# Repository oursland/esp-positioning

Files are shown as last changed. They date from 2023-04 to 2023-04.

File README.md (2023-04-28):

# Positioning via IMU-aided WiFi FTM and UWB on an ESP32-S3

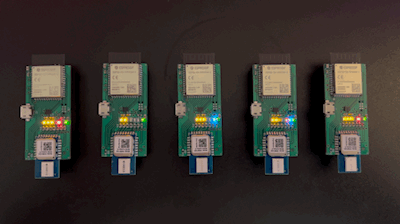
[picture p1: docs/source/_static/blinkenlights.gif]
blinkenlights


## Overview

There is ample research into the accuracy of Ulra Wideband (UWB)-based ranging and positioning, WiFi Fine Timing Measurements (WiFi FTM)-based ranging and positioning, and an Inertial Measurement Unit (IMU) augmentation of such systems.  Most of the work was performed with purpose-designed systems or smartphones, but very little was performed using Espressif SoCs including the ESP32-S3.

Based on the findings of previous works, it's expected that WiFi FTM may be only valuable for positioning information to about 1 meter accuracy while UWB sensors can provide measurements accurate down to around 10 centimeters.  UWB has limited range, particularly in indoor and cluttered environments where the signals fail to penetrate through walls or other obstacles.  This suggests that if accuracy is a requirement, it may be required to install a UWB transciever but also utilize WiFi FTM to provide rough positioning should the UWB signal be lost.

Sensor fusion and state estimation through Kalman filtering can provide better positioning estimates over naive approaches using WiFi FTM, UWB, or IMU measurements alone.  Previous research have been performed using Extended Kalman Filtering (EKF) and Unscented Kalman Filter (UKF) approaches, but publications for Invariant Extended Kalman Filter (InEKF) have not been identified.

### Questions

1. Given the utility for low-cost, low-power, and reduced bill-of-materials positioning for small, low-cost robots, can we use the ESP32-S3's WiFi Fine Timing Measurements (WiFi FTM) in 802.11mc standard and an IMU for positioning without additional sensors?

2. Will the inclusion of a UWB sensor bring sufficient value to offset their additional cost, complexity, and power consumption?

3. Can the redundancy in Time Difference of Arrival (TDOA) measurements from WiFi FTM and UWB be used to improve accuracy beyond either WiFi FTM or UWB alone?

## Objective

This experiment is to compare and contrast position estimation of systems:

    1. IMU and WiFi FTM
    2. IMU and UWB
    3. IMU with WiFi FTM and UWB

## Experiment Design

To perform this experiment, a custom design was created using:

* Espressif ESP32-S3-WROOM-2 module
* STMicroelectronics ISM330DHCX IMU
* Qorvo DWM1000 UWB module
* 2 AAA battery holder

Circuit Diagram and PCB Layout can be found in the [`kicad/`](kicad/) directory.

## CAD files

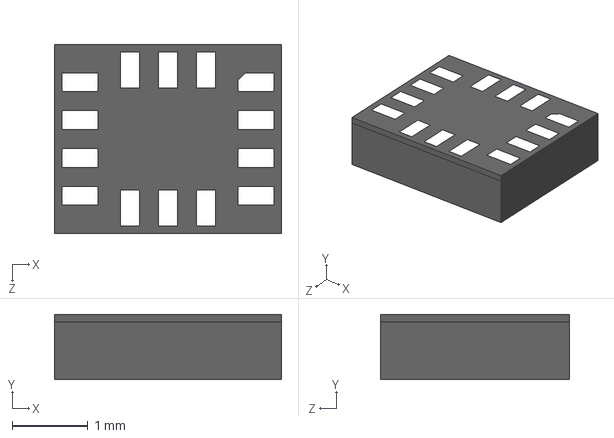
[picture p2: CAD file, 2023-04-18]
kicad/3D/ISM330DHCXTR.stp
3.00 x 0.86 x 2.50 mm

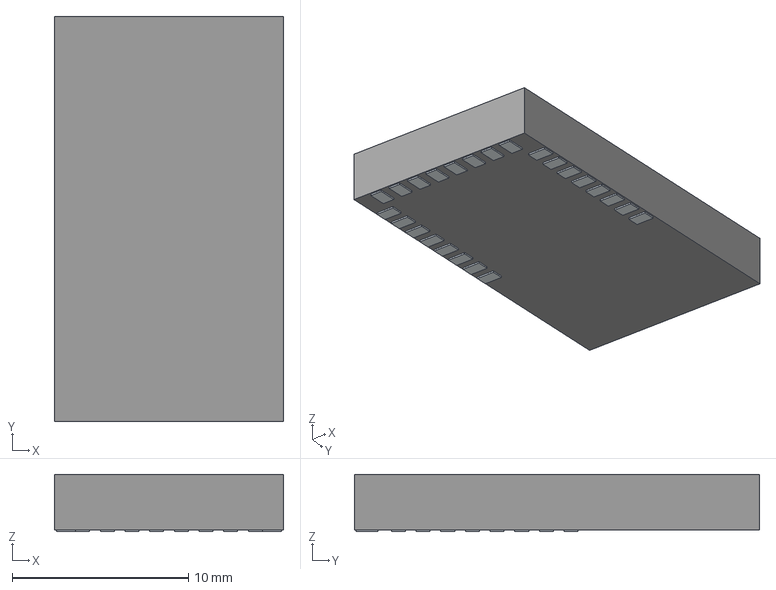
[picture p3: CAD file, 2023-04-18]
kicad/3D/DWM1000.stp
13.0 x 23.0 x 3.25 mm
Pins

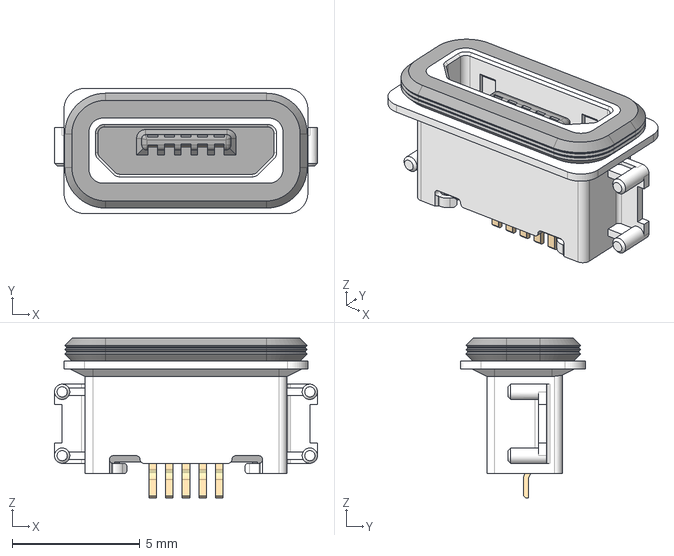
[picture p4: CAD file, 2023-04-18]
kicad/3D/USB3500-30-A.stp
10.3 x 4.90 x 6.25 mm
ÇÐ³ý-ÀÉì3
µ¹½Ç2

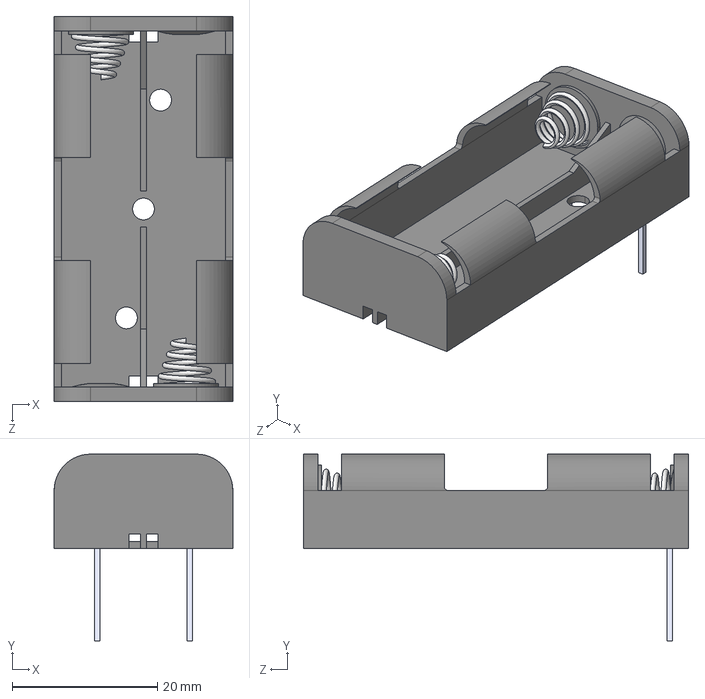
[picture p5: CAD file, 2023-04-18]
kicad/3D/2468.stp
24.6 x 25.7 x 53.0 mm

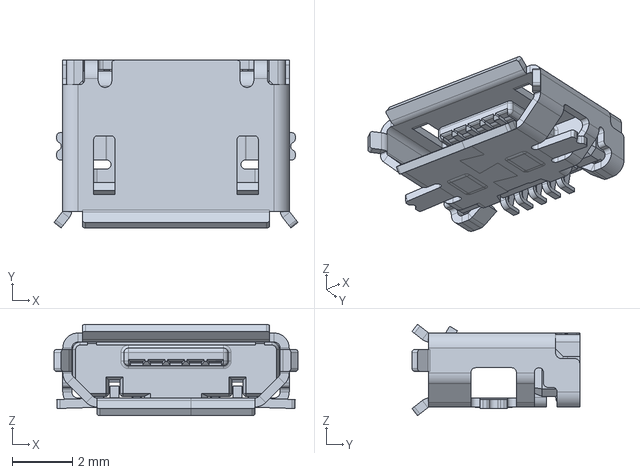
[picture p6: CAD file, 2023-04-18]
kicad/3D/10104110-0001LF.stp
8.08 x 5.56 x 3.03 mm

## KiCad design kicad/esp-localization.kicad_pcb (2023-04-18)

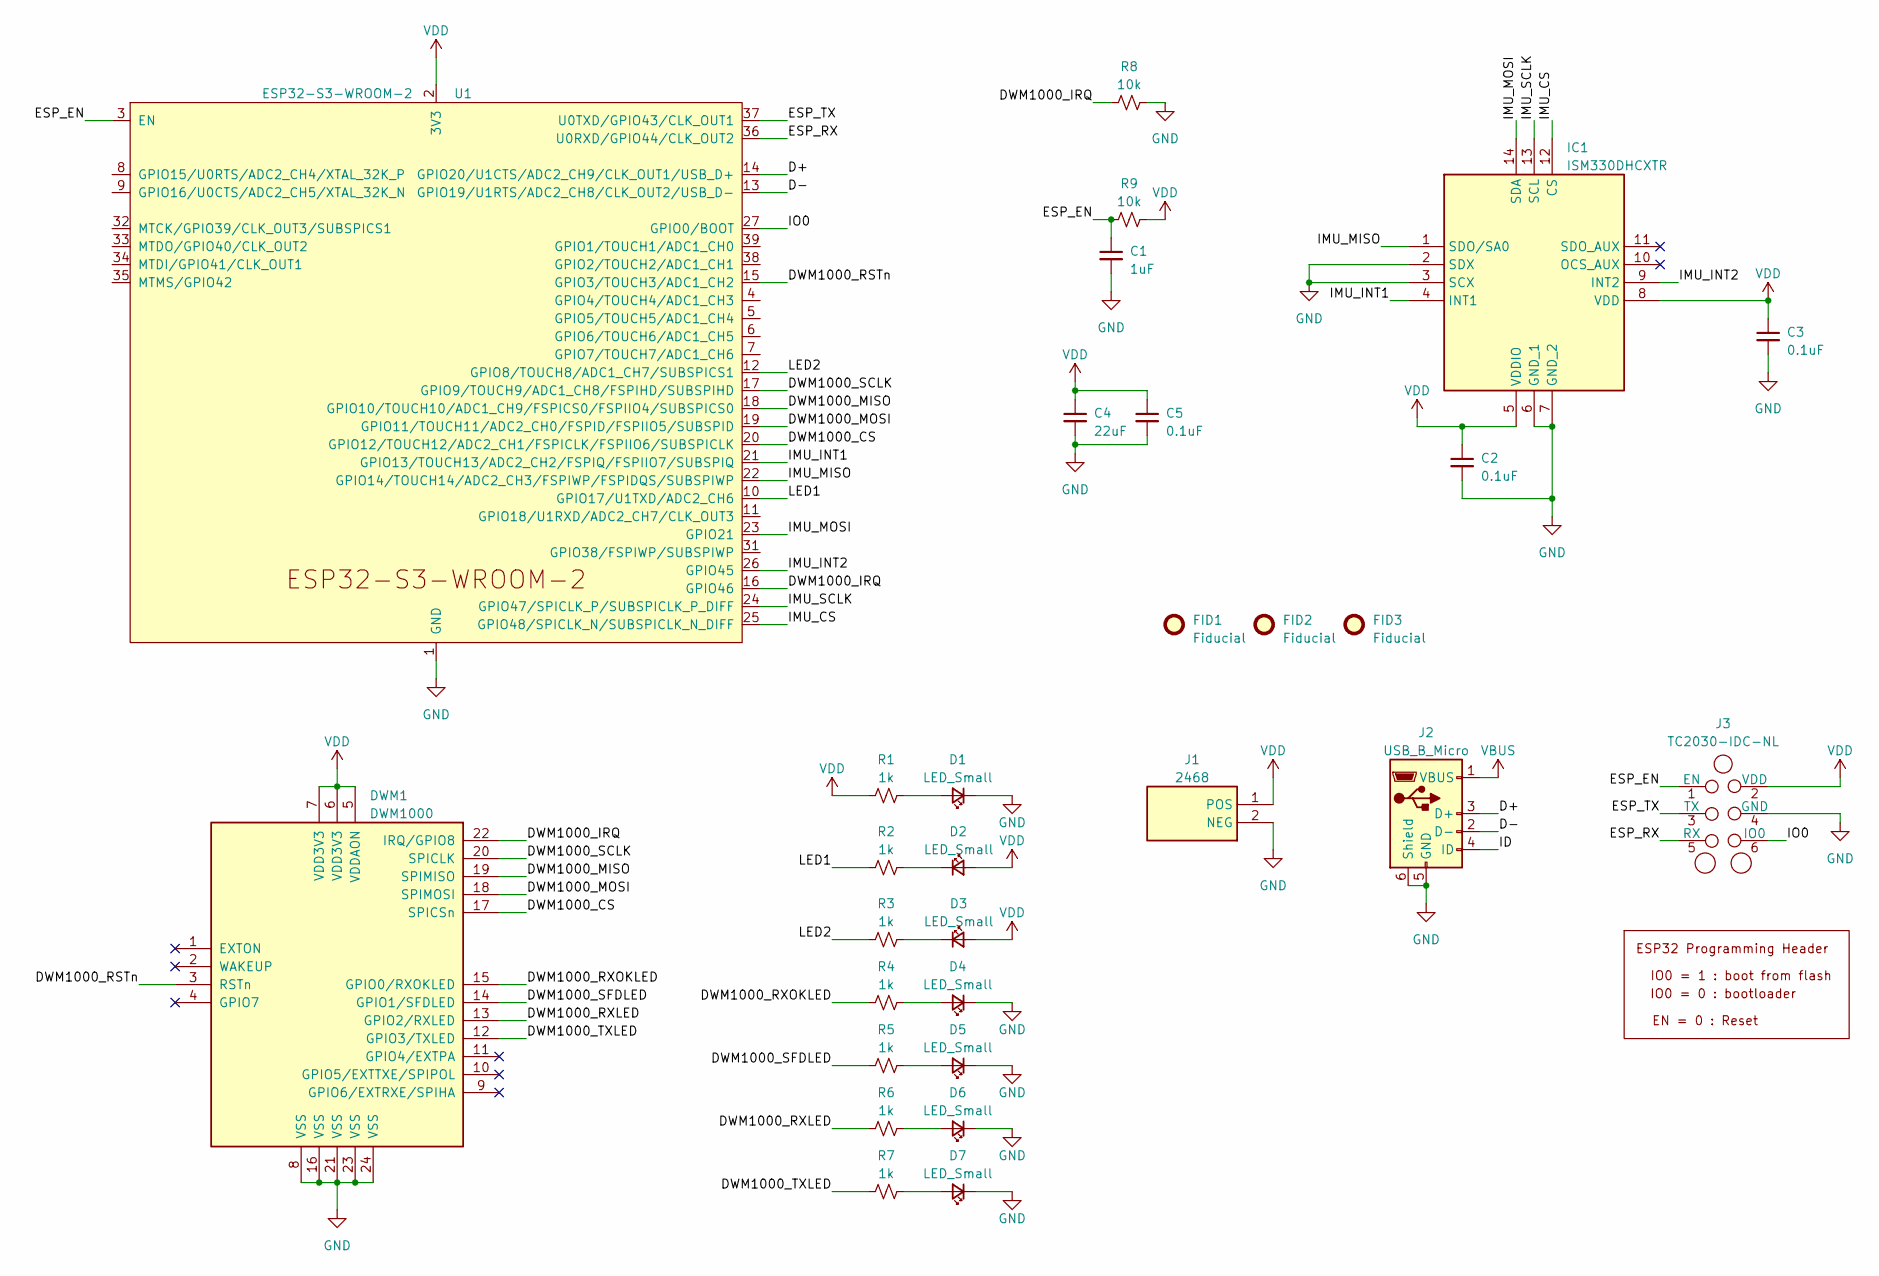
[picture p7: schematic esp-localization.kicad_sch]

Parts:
C1: 1uF; C_0805_2012Metric
C2, C3, C5: 0.1uF; C_0603_1608Metric
C4: 22uF; C_0805_2012Metric
D1, D2, D3, D4, D5, D6, D7: LED_Small; LED_0603_1608Metric
DWM1: DWM1000
FID1, FID2, FID3: Fiducial; Fiducial_0.5mm_Mask1mm
IC1: ISM330DHCXTR; LGA-14_2.5X3X0.86_; Mouser Part Number 511-ISM330DHCXTR
J1: 2468; Mouser Part Number 534-2468
J2: USB_B_Micro; USB_Micro-B_Amphenol_10104110_Horizontal
J3: TC2030-IDC-NL_ESP; Tag-Connect_TC2030-IDC-NL_2x03_P1.27mm_Vertical
R1, R2, R3, R4, R5, R6, R7: 1k; R_0603_1608Metric
R8, R9: 10k; R_0603_1608Metric
U1: ESP32-S3-WROOM-2

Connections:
/D+: J2.3 (D+), U1.14 (GPIO20/U1CTS/ADC2_CH9/CLK_OUT1/USB_D+)
/D-: J2.2 (D-), U1.13 (GPIO19/U1RTS/ADC2_CH8/CLK_OUT2/USB_D-)
/DWM1000_CS: DWM1.17 (SPICSn), U1.20 (GPIO12/TOUCH12/ADC2_CH1/FSPICLK/FSPIIO6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)
/DWM1000_IRQ: DWM1.22 (IRQ/GPIO8), R8.1, U1.16 (GPIO46)
/DWM1000_MISO: DWM1.19 (SPIMISO), U1.18 (GPIO10/TOUCH10/ADC1_CH9/FSPICS0/FSPIIO4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)
/DWM1000_MOSI: DWM1.18 (SPIMOSI), U1.19 (GPIO11/TOUCH11/ADC2_CH0/FSPID/FSPIIO5/S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)
/DWM1000_RSTn: DWM1.3 (RSTn), U1.15 (GPIO3/TOUCH3/ADC1_CH2)
/DWM1000_RXLED: DWM1.13 (GPIO2/RXLED), R6.1
/DWM1000_RXOKLED: DWM1.15 (GPIO0/RXOKLED), R4.1
/DWM1000_SCLK: DWM1.20 (SPICLK), U1.17 (GPIO9/TOUCH9/ADC1_CH8/FSPIHD/SUBSPIHD)
/DWM1000_SFDLED: DWM1.14 (GPIO1/SFDLED), R5.1
/DWM1000_TXLED: DWM1.12 (GPIO3/TXLED), R7.1
/ESP_EN: C1.1, J3.1 (EN), R9.1, U1.3 (EN)
/ESP_RX: J3.5 (RX), U1.36 (U0RXD/GPIO44/CLK_OUT2)
/ESP_TX: J3.3 (TX), U1.37 (U0TXD/GPIO43/CLK_OUT1)
/ID: J2.4 (ID)
/IMU_CS: IC1.12 (CS), U1.25 (GPIO48/SPICLK_N/SUBSPICLK_N_DIFF)
/IMU_INT1: IC1.4 (INT1), U1.21 (GPIO13/TOUCH13/ADC2_CH2/FSPIQ/FSPIIO7/S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)
/IMU_INT2: IC1.9 (INT2), U1.26 (GPIO45)
/IMU_MISO: IC1.1 (SDO/SA0), U1.22 (GPIO14/TOUCH14/ADC2_CH3/FSPIWP/FSPIDQS/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)
/IMU_MOSI: IC1.14 (SDA), U1.23 (GPIO21)
/IMU_SCLK: IC1.13 (SCL), U1.24 (GPIO47/SPICLK_P/SUBSPICLK_P_DIFF)
/IO0: J3.6 (IO0), U1.27 (GPIO0/BOOT)
/LED1: R2.1, U1.10 (GPIO17/U1TXD/ADC2_CH6)
/LED2: R3.1, U1.12 (GPIO8/TOUCH8/ADC1_CH7/SUBSPICS1)
GND: C1.2, C2.2, C3.2, C4.2, C5.2, D1.1 (K), D4.1 (K), D5.1 (K), D6.1 (K), D7.1 (K), DWM1.8 (VSS), DWM1.16 (VSS), DWM1.21 (VSS), DWM1.23 (VSS), DWM1.24 (VSS), IC1.2 (SDX), IC1.3 (SCX), IC1.6 (GND_1), IC1.7 (GND_2), J1.2 (NEG), J2.5 (GND), J2.6 (Shield), J3.4 (GND), R8.2, U1.1 (GND), U1.40 (GND), U1.41 (GND)
unnamed: D1.2 (A), R1.2
unnamed: D2.1 (K), R2.2
unnamed: D3.1 (K), R3.2
unnamed: D4.2 (A), R4.2
unnamed: D5.2 (A), R5.2
unnamed: D6.2 (A), R6.2
unnamed: D7.2 (A), R7.2
VBUS: J2.1 (VBUS)
VDD: C2.1, C3.1, C4.1, C5.1, D2.2 (A), D3.2 (A), DWM1.5 (VDDAON), DWM1.6 (VDD3V3), DWM1.7 (VDD3V3), IC1.5 (VDDIO), IC1.8 (VDD), J1.1 (POS), J3.2 (VDD), R1.1, R9.2, U1.2 (3V3)

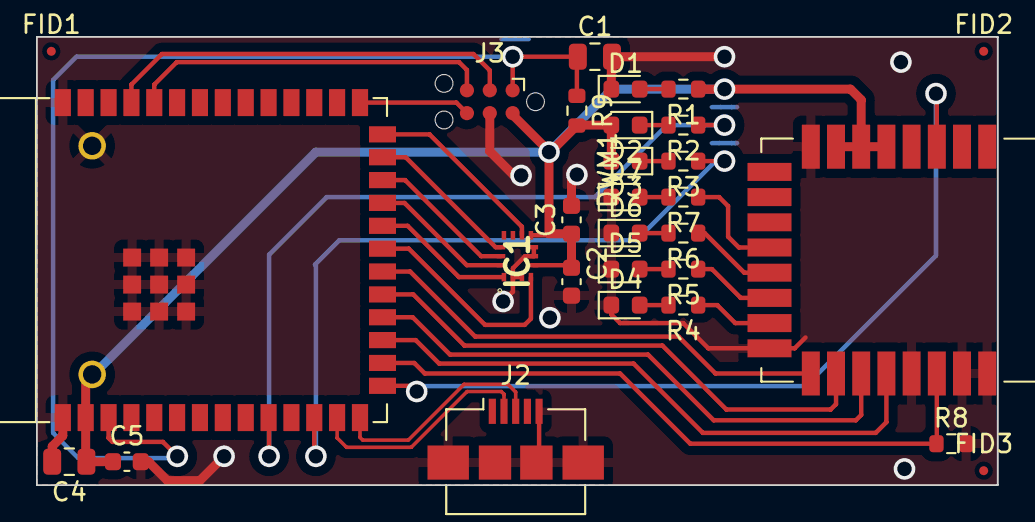
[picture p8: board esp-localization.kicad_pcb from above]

Board: 2 copper layers, 53.4 x 24.9 mm, 30 parts (1 on the bottom side), 33 nets.

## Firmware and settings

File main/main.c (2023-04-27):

#include <stdio.h>
#include <stdlib.h>
#include <string.h>
#include <inttypes.h>

#include "sdkconfig.h"

#include "freertos/FreeRTOS.h"
#include "freertos/queue.h"
#include "freertos/task.h"

#include "esp_chip_info.h"
#include "esp_flash.h"
#include "esp_log.h"
#include "esp_mac.h"
#include "esp_timer.h"
#include "nvs_flash.h"

#include "driver/gpio.h"

#include "common.h"
#include "dw1000-task.h"
#include "ftm-task.h"
#include "ism330dhcx-task.h"

#define TAG         "app_main"

// LEDs are active low
#define LED1        GPIO_NUM_17
#define LED2        GPIO_NUM_8

void app_main()
{
    /* Print chip information */
    esp_chip_info_t chip_info;
    uint32_t flash_size;
    esp_chip_info(&chip_info);
    ESP_LOGI(TAG, "This is %s chip with %d CPU core(s), WiFi%s%s%s, ",
        CONFIG_IDF_TARGET,
        chip_info.cores,
        (chip_info.features & CHIP_FEATURE_BT) ? "/BT" : "",
        (chip_info.features & CHIP_FEATURE_BLE) ? "/BLE" : "",
        (chip_info.features & CHIP_FEATURE_IEEE802154) ? ", 802.15.4 (Zigbee/Thread)" : "");

    unsigned major_rev = chip_info.revision / 100;
    unsigned minor_rev = chip_info.revision % 100;
    ESP_LOGI(TAG, "silicon revision v%d.%d, ", major_rev, minor_rev);
    if(esp_flash_get_size(NULL, &flash_size) != ESP_OK) {
        printf("Get flash size failed");
        return;
    }

    ESP_LOGI(TAG, "%" PRIu32 "MB %s flash", flash_size / (uint32_t)(1024 * 1024),
        (chip_info.features & CHIP_FEATURE_EMB_FLASH) ? "embedded" : "external");

    ESP_LOGI(TAG, "Minimum free heap size: %" PRIu32 " bytes", esp_get_minimum_free_heap_size());

    uint8_t mac[6];
    ESP_ERROR_CHECK(esp_read_mac(mac, ESP_MAC_BASE));
    ESP_LOGI(TAG, "MAC address: [%02X:%02X:%02X:%02X:%02X:%02X]", mac[0], mac[1], mac[2], mac[3], mac[4], mac[5]);

    esp_err_t ret = nvs_flash_init();
    if(ret == ESP_ERR_NVS_NO_FREE_PAGES || ret == ESP_ERR_NVS_NEW_VERSION_FOUND) {
        ESP_ERROR_CHECK(nvs_flash_erase());
        ret = nvs_flash_init();
    }
    ESP_ERROR_CHECK(ret);

    // LEDS
    bool led1 = 0;
    bool led2 = 0;

    gpio_set_direction(LED1, GPIO_MODE_OUTPUT);
    gpio_set_level(LED1, led1);

    gpio_set_direction(LED2, GPIO_MODE_OUTPUT);
    gpio_set_level(LED2, led2);

    task_t ism330dhcx_task;
    task_t ftm_task;
    task_t dw1000_task;

    QueueHandle_t main_queue = xQueueCreate(10, sizeof(event_type_t));

    ism330dhcx_task.task_queue = xQueueCreate(10, sizeof(event_type_t));
    ism330dhcx_task.main_queue = main_queue;
    ism330dhcx_task.task_handle = xTaskCreate(ism330dhcx_task_func, "ism330dhcx_task", 4096, &ism330dhcx_task, 1, NULL);

    ftm_task.task_queue = xQueueCreate(10, sizeof(event_type_t));
    ftm_task.main_queue = main_queue;
    ftm_task.task_handle = xTaskCreate(ftm_task_func, "ftm_task", 4096, &ftm_task, 1, NULL);

    dw1000_task.task_queue = xQueueCreate(10, sizeof(event_type_t));
    dw1000_task.main_queue = main_queue;
    dw1000_task.task_handle = xTaskCreate(dw1000_task_func, "dw1000_task", 4096, &dw1000_task, 1, NULL);

    for(;;) {
        led1 = !led1;
        gpio_set_level(LED1, led1);

        vTaskDelay(pdMS_TO_TICKS(100));
    }
}

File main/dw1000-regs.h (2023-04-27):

#pragma once

/*
 * Driver for decaWave DW1000 802.15.4 UWB radio chip.
 *
 * Copyright (c) 2016 Bitcraze AB
 * Converted to C from  the Decawave DW1000 library for arduino.
 * which is Copyright (c) 2015 by Thomas Trojer <thomas@trojer.net>
 *
 * Licensed under the Apache License, Version 2.0 (the "License");
 * you may not use this file except in compliance with the License.
 * You may obtain a copy of the License at
 *
 *     http://www.apache.org/licenses/LICENSE-2.0
 *
 * Unless required by applicable law or agreed to in writing, software
 * distributed under the License is distributed on an "AS IS" BASIS,
 * WITHOUT WARRANTIES OR CONDITIONS OF ANY KIND, either express or implied.
 * See the License for the specific language governing permissions and
 * limitations under the License.
 */

// Time resolution in micro-seconds of time based registers/values.
// Each bit in a timestamp counts for a period of approx. 15.65ps
#define TIME_RES 0.000015650040064103
#define TIME_RES_INV 63897.6

// Speed of radio waves [m/s] * timestamp resolution [~15.65ps] of DW1000
#define DISTANCE_OF_RADIO 0.0046917639786159f
#define DISTANCE_OF_RADIO_INV 213.139451293f

// time stamp byte length
#define LEN_STAMP 5

// enum to determine RX or TX mode of device
#define IDLE_MODE 0x00
#define RX_MODE 0x01
#define TX_MODE 0x02

// used for SPI ready w/o actual writes
#define JUNK 0x00

// no sub-address for register write
#define NO_SUB 0x00

// device id register
#define DEV_ID 0x00
#define LEN_DEV_ID 4

// extended unique identifier register
#define EUI 0x01
#define LEN_EUI 8

// PAN identifier, short address register
#define PANADR 0x03
#define LEN_PANADR 4

// device configuration register
#define SYS_CFG 0x04
#define LEN_SYS_CFG 4
#define FFEN_BIT 0
#define FFBC_BIT 1
#define FFAB_BIT 2
#define FFAD_BIT 3
#define FFAA_BIT 4
#define FFAM_BIT 5
#define FFAR_BIT 6
#define SPI_EDGE_BIT 10
#define DIS_DRXB_BIT 12
#define DIS_STXP_BIT 18
#define HIRQ_POL_BIT 9
#define RXAUTR_BIT 29
#define PHR_MODE_SUB 16
#define LEN_PHR_MODE_SUB 2
#define RXM110K_BIT 22
#define RXWTOE_BIT 28

// device control register
#define SYS_CTRL 0x0D
#define LEN_SYS_CTRL 4
#define SFCST_BIT 0
#define TXSTRT_BIT 1
#define TXDLYS_BIT 2
#define TRXOFF_BIT 6
#define WAIT4RESP_BIT 7
#define RXENAB_BIT 8
#define RXDLYS_BIT 9

// system event status register
#define SYS_STATUS 0x0F
#define LEN_SYS_STATUS 5
#define CPLOCK_BIT 1
#define AAT_BIT 3
#define TXFRB_BIT 4
#define TXPRS_BIT 5
#define TXPHS_BIT 6
#define TXFRS_BIT 7
#define RXPRD_BIT 8
#define MRXSFDD_BIT 9
#define LDEDONE_BIT 10
#define MRXPHD_BIT 11
#define RXPHE_BIT 12
#define RXDFR_BIT 13
#define RXFCG_BIT 14
#define RXFCE_BIT 15
#define RXRFSL_BIT 16
#define RXRFTO_BIT 17
#define LDEERR_BIT 18
// Bit 19 is reserved
#define RXOVRR_BIT 20
#define RXPTO_BIT 21
#define RFPLL_LL_BIT 24
#define CLKPLL_LL_BIT 25
#define RXSFDTO_BIT 26
#define AFFREJ_BIT 29

// Helper masks. See: See: https://github.com/Decawave/dwm1001-examples/blob/master/deca_driver/deca_regs.h
// All RX errors mask
#define SYS_STATUS_ALL_RX_ERR (1 << RXPHE_BIT | 1 << RXFCE_BIT | 1 << RXRFSL_BIT | 1 << RXSFDTO_BIT | 1 << AFFREJ_BIT | 1 << LDEERR_BIT)
// User defined RX timeouts (frame wait timeout and preamble detect timeout) mask
#define SYS_STATUS_ALL_RX_TO (1 << RXRFTO_BIT | 1 << RXPTO_BIT)
// All RX events after a correct packet reception mask
#define SYS_STATUS_ALL_RX_GOOD (1 << RXDFR_BIT | 1 << RXFCG_BIT | 1 << RXPRD_BIT | 1 << MRXSFDD_BIT | 1 << MRXPHD_BIT | 1 << LDEDONE_BIT)
// All TX events mask
#define SYS_STATUS_ALL_TX (1 << AAT_BIT | 1 << TXFRB_BIT | 1 << TXPRS_BIT | 1 << TXPHS_BIT | 1 << TXFRS_BIT)

// GPIO control register
#define GPIO_CTRL 0x26
#define GPIO_MODE_SUB 0x00
#define LEN_GPIO_MODE 4
#define GPIO_DIR_SUB 0x08
#define LEN_GPIO_DIR 4


// system event mask register
// NOTE: uses the bit definitions of SYS_STATUS (below 32)
#define SYS_MASK 0x0E
#define LEN_SYS_MASK 4

// system time counter
#define SYS_TIME 0x06
#define LEN_SYS_TIME LEN_STAMP

// RX timestamp register
#define RX_TIME 0x15
#define LEN_RX_TIME 14
#define RX_STAMP_SUB 0x00
#define FP_AMPL1_SUB 0x07
#define LEN_RX_STAMP LEN_STAMP
#define LEN_FP_AMPL1 2

// RX frame quality
#define RX_FQUAL 0x12
#define LEN_RX_FQUAL 8
#define STD_NOISE_SUB 0x00
#define FP_AMPL2_SUB 0x02
#define FP_AMPL3_SUB 0x04
#define CIR_PWR_SUB 0x06
#define LEN_STD_NOISE 2
#define LEN_FP_AMPL2 2
#define LEN_FP_AMPL3 2
#define LEN_CIR_PWR 2

// TX timestamp register
#define TX_TIME 0x17
#define LEN_TX_TIME 10
#define TX_STAMP_SUB 0
#define LEN_TX_STAMP LEN_STAMP

// timing register (for delayed RX/TX)
#define DX_TIME 0x0A
#define LEN_DX_TIME LEN_STAMP

// transmit data buffer
#define TX_BUFFER 0x09
#define LEN_TX_BUFFER 1024
#define LEN_UWB_FRAMES 127
#define LEN_EXT_UWB_FRAMES 1023

// Receive frame ait timeout period
#define RX_FWTO 0x0C

// RX frame info
#define RX_FINFO 0x10
#define LEN_RX_FINFO 4

// receive data buffer
#define RX_BUFFER 0x11
#define LEN_RX_BUFFER 1024

// transmit control
#define TX_FCTRL 0x08
#define LEN_TX_FCTRL 5

// channel control
#define CHAN_CTRL 0x1F
#define LEN_CHAN_CTRL 4
#define DWSFD_BIT 17
#define TNSSFD_BIT 20
#define RNSSFD_BIT 21

// user-defined SFD
#define USR_SFD 0x21
#define LEN_USR_SFD 41
#define SFD_LENGTH_SUB 0x00
#define LEN_SFD_LENGTH 1

// OTP control (for LDE micro code loading only)
#define OTP_IF 0x2D
#define OTP_ADDR_SUB 0x04
#define OTP_CTRL_SUB 0x06
#define OTP_RDAT_SUB 0x0A
#define LEN_OTP_ADDR 2
#define LEN_OTP_CTRL 2
#define LEN_OTP_RDAT 4

// AGC_TUNE1/2 (for re-tuning only)
#define AGC_TUNE 0x23
#define AGC_TUNE1_SUB 0x04
#define AGC_TUNE2_SUB 0x0C
#define AGC_TUNE3_SUB 0x12
#define LEN_AGC_TUNE1 2
#define LEN_AGC_TUNE2 4
#define LEN_AGC_TUNE3 2

// DRX_TUNE2 (for re-tuning only)
#define DRX_TUNE 0x27
#define DRX_TUNE0b_SUB 0x02
#define DRX_TUNE1a_SUB 0x04
#define DRX_TUNE1b_SUB 0x06
#define DRX_TUNE2_SUB 0x08
#define DRX_TUNE4H_SUB 0x26
#define LEN_DRX_TUNE0b 2
#define LEN_DRX_TUNE1a 2
#define LEN_DRX_TUNE1b 2
#define LEN_DRX_TUNE2 4
#define LEN_DRX_TUNE4H 2

// LDE_CFG1 (for re-tuning only)
#define LDE_IF 0x2E
#define LDE_CFG1_SUB 0x0806
#define LDE_RXANTD_SUB 0x1804
#define LDE_CFG2_SUB 0x1806
#define LDE_REPC_SUB 0x2804
#define LEN_LDE_CFG1 1
#define LEN_LDE_CFG2 2
#define LEN_LDE_REPC 2
#define LEN_LDE_RXANTD 2

// TX_POWER (for re-tuning only)
#define TX_POWER 0x1E
#define LEN_TX_POWER 4

// RF_CONF (for re-tuning only)
#define RF_CONF 0x28
#define RF_RXCTRLH_SUB 0x0B
#define RF_TXCTRL_SUB 0x0C
#define LEN_RF_RXCTRLH 1
#define LEN_RF_TXCTRL 4

// TX_CAL (for re-tuning only)
#define TX_CAL 0x2A
#define TC_PGDELAY_SUB 0x0B
#define LEN_TC_PGDELAY 1

// FS_CTRL (for re-tuning only)
#define FS_CTRL 0x2B
#define FS_PLLCFG_SUB 0x07
#define FS_PLLTUNE_SUB 0x0B
#define FS_XTALT_SUB 0x0E
#define LEN_FS_PLLCFG 4
#define LEN_FS_PLLTUNE 1
#define LEN_FS_XTALT 1
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

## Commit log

2023-04-18 Add Hello World sample code.
2023-04-18 Add kicad files.
    [10104110-0001LF.stp, 2468.stp, DWM1000.stp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]
2023-04-27 Add ISM330DHCX and DW1000 drivers.

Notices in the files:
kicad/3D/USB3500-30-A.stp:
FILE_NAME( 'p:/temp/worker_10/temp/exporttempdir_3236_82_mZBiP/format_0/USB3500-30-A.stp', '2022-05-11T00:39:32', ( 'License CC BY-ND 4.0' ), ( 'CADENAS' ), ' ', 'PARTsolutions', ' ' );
